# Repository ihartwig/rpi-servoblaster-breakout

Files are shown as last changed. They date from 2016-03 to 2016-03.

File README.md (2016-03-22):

# rpi-servoblaster-breakout

[Order from DirtyPCB now!](http://dirtypcbs.com/view.php?share=18349&accesskey=)

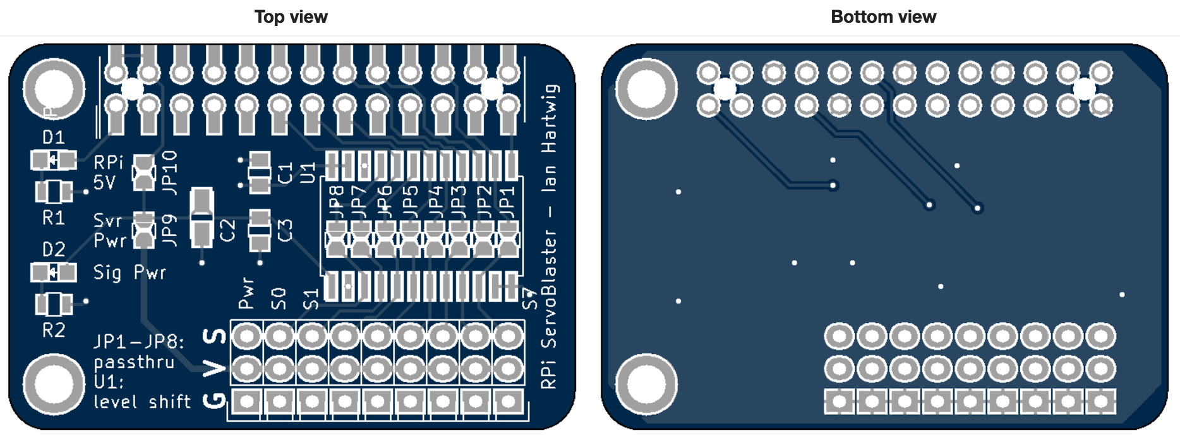
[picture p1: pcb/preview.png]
board rendering


Servo breakout for RPi 0/1/2 based on the [servoblaster](https://github.com/richardghirst/PiBits/tree/master/ServoBlaster)/pi-blaster software. This board supports the default location of 8 servos. In most cases it passively wires the servos to the right pins with shared power and ground rails. A level shifter can be added if your servos require a logic pulse above the RPi's 3.3V. The board is small to reduce cost and fit on both Pi 1 and Pi 0.

You'll need a stacking female 2x13 header to connect to the RPi, commonly found at [Adafruit](https://www.adafruit.com/products/1112) or [Toby Electronics](http://www.toby.co.uk/content/catalogue/products.aspx?series=REF-18xxxx-0x). This header can be soldered directly to the board or fed into a [bottom-entry SMT header](http://www.toby.co.uk/content/catalogue/products.aspx?series=REF-1826xx-0x) soldered onto the top.

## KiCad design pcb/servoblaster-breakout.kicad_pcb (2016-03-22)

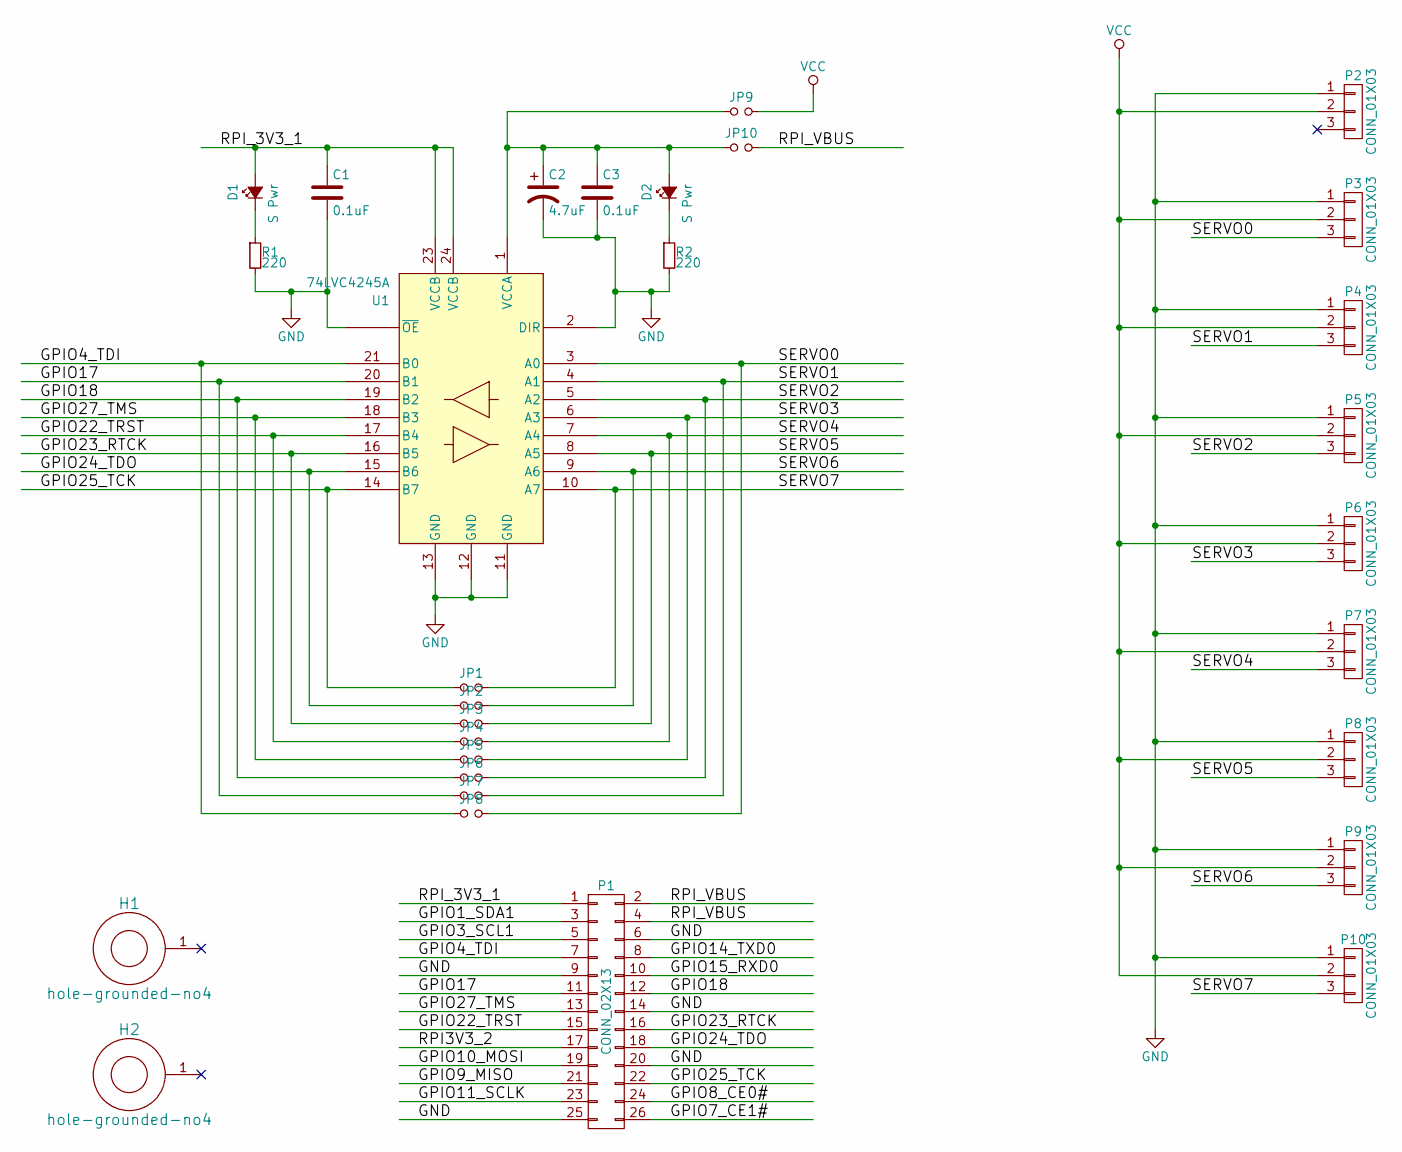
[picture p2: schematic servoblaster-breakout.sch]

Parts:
C1, C3: 0.1uF; C_0805
C2: 4.7uF; TantalC_SizeA_EIA-3216_Reflow
D1, D2: S Pwr; LED-0805
H1, H2: hole-grounded-no4; hole-no4
JP1, JP2, JP3, JP4, JP5, JP6, JP7, JP8, JP9, JP10: Jumper_NO_Small; SB_0805
P1: CONN_02X13; Pin_Header_Straight_TH-SMT_2x13
P2, P3, P4, P5, P6, P7, P8, P9, P10: CONN_01X03; Pin_Header_Straight_1x03
R1, R2: 220; R_0805
U1: 74LVC4245A; SOIC-24_7.5x15.4mm_Pitch1.27mm

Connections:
/GPIO1_SDA1: P1.3
/GPIO3_SCL1: P1.5
/GPIO4_TDI: JP8.1, P1.7, U1.21 (B0)
/GPIO7_CE1#: P1.26
/GPIO8_CE0#: P1.24
/GPIO9_MISO: P1.21
/GPIO10_MOSI: P1.19
/GPIO11_SCLK: P1.23
/GPIO14_TXD0: P1.8
/GPIO15_RXD0: P1.10
/GPIO17: JP7.1, P1.11, U1.20 (B1)
/GPIO18: JP6.1, P1.12, U1.19 (B2)
/GPIO22_TRST: JP4.1, P1.15, U1.17 (B4)
/GPIO23_RTCK: JP3.1, P1.16, U1.16 (B5)
/GPIO24_TDO: JP2.1, P1.18, U1.15 (B6)
/GPIO25_TCK: JP1.1, P1.22, U1.14 (B7)
/GPIO27_TMS: JP5.1, P1.13, U1.18 (B3)
/RPI3V3_2: P1.17
/RPI_3V3_1: C1.1, D1.2 (A), P1.1, U1.23 (VCCB), U1.24 (VCCB)
/RPI_VBUS: JP10.2, P1.2, P1.4
/SERVO0: JP8.2, P3.3, U1.3 (A0)
/SERVO1: JP7.2, P4.3, U1.4 (A1)
/SERVO2: JP6.2, P5.3, U1.5 (A2)
/SERVO3: JP5.2, P6.3, U1.6 (A3)
/SERVO4: JP4.2, P7.3, U1.7 (A4)
/SERVO5: JP3.2, P8.3, U1.8 (A5)
/SERVO6: JP2.2, P9.3, U1.9 (A6)
/SERVO7: JP1.2, P10.3, U1.10 (A7)
GND: C1.2, C2.2, C3.2, P1.6, P1.9, P1.14, P1.20, P1.25, P2.1, P3.1, P4.1, P5.1, P6.1, P7.1, P8.1, P9.1, P10.1, R1.2, R2.2, U1.2 (DIR), U1.11 (GND), U1.12 (GND), U1.13 (GND), U1.22, U1.~ (~OE)
unnamed: C2.1, C3.1, D2.2 (A), JP9.1, JP10.1, U1.1 (VCCA)
unnamed: D1.1 (K), R1.1
unnamed: D2.1 (K), R2.1
VCC: JP9.2, P2.2, P3.2, P4.2, P5.2, P6.2, P7.2, P8.2, P9.2, P10.2

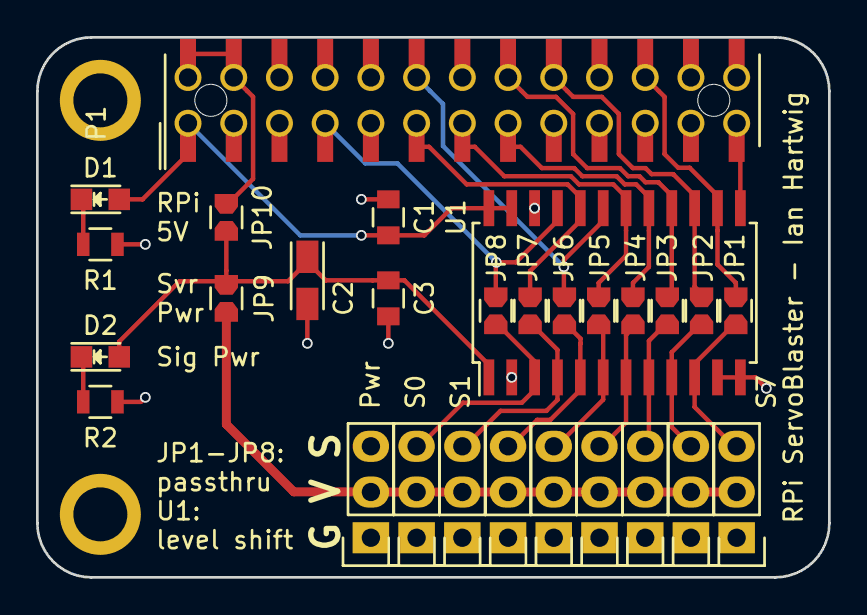
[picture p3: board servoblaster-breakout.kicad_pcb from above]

Board: 2 copper layers, 44.0 x 30.0 mm, 30 parts (0 on the bottom side), 23 nets.

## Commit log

2016-03-17 rev 1 board layout
    [servoblaster-breakout-B.Cu.gbl, servoblaster-breakout-B.Mask.gbs, servoblaster-breakout-B.Paste.gbp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]
2016-03-22 rename repo and board directory
    [servoblaster-breakout-B.Cu.gbl, servoblaster-breakout-B.Mask.gbs, servoblaster-breakout-B.Paste.gbp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]
2016-03-22 update solder bridge part to not have paste
    [servoblaster-breakout-B.Cu.gbl, servoblaster-breakout-B.Mask.gbs, servoblaster-breakout-B.Paste.gbp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]
